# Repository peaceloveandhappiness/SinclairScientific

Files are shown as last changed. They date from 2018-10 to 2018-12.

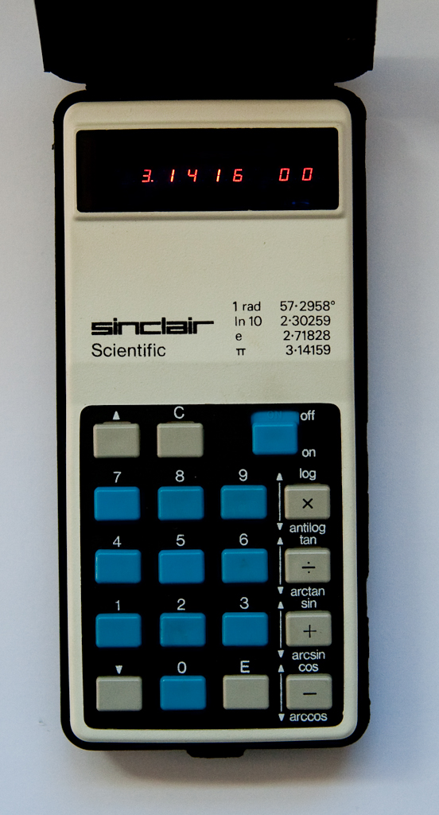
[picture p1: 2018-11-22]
artwork/SinclairScientific.jpg

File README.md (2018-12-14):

# Sinclair Scientific

This is a recreation of the original 1974 Scientific Calculator, the first affordable calculator with more than just + - ÷ ×.

Hewlett Packard had released it’s first “scientific” calculator two years earlier, and despite it costing literally as much as a fairly nice used car, it was a very successful product. Texas Instruments, on the other hand, had a widely available “four function” chip that was the heart of every cheap digital calculator, but was limited to adding, subtracting, multiplying and dividing, with limited precision.

Enter Clive Sinclair and Nigel Searle, who figured out how to use the ultra-meager 320 bytes of instruction space on that TI device to implement sine, asin, cos, acos, tan, atan, log, and antilog, in scientific notation! A feat of hacking that’s mystifying even now.

We have recreated this hallowed machine using an emulator of the TI chip, running the original instructions, at the original speed. It has lots of quirks and issues, some of which are described in this manual, some of which we had fun exploring. Far from diminishing it, these idiosyncrasies, in reality, highlight the amazing achievement that this device represents.

Enjoy!

## Inspiration

This work was inspired by and largely based upon [ArduinoEnigma's similar project](https://gitlab.com/arduinoenigma/ArduinoNanoSinclairScientificCalculator), which was inspired by [Ken Shirriff's Sinclair Scientific Calculator Simulator](http://righto.com/sinclair). The hardware design is based upon [Adafruit's Feather M0](https://github.com/adafruit/Adafruit-Feather-M0-Basic-Proto-PCB), as well as [ArduinoEnigma's hardware designs](https://hackaday.io/project/91895-sinclair-scientific-calculator-emulator). The firmware used in this project is based on [ArduinoEnigma's SinclairScientific7 code](https://gitlab.com/arduinoenigma/ArduinoNanoSinclairScientificCalculator/tree/master/SinclairScientific7) and [Adafruit's SAMD toolchain](https://github.com/adafruit/ArduinoCore-samd).

* [Ken Shirriff's Simulator](http://files.righto.com/calculator/sinclair_scientific_simulator.html)
* [ArduinoEnigma's Arduino Code](https://github.com/arduinoenigma/ArduinoNanoSinclairScientificCalculator)
* [ArduinoEnigma's Hackster Guide](https://www.hackster.io/arduinoenigma/sinclair-scientific-calculator-emulator-a11dba)
* [ArduinoEnigma's Hackaday Guide](https://hackaday.io/project/91895-sinclair-scientific-calculator-emulator)
* [ArduinoEnigma's Tindie Page](https://www.tindie.com/products/ArduinoEnigma/sinclair-scientific-calculator-emulator/)
* [Adafruit's Feather M0](https://github.com/adafruit/Adafruit-Feather-M0-Basic-Proto-PCB)

## Credits

* Thank you Joerg Woerner of [Datamath Calculator Museum](www.datamath.org/) for finding and scanning the original [Sinclair Scientific Operating Manual](www.datamath.net/Manuals_Others/Sinclair_Scientific_GB.pdf).
* Thank you [Katherine Wasserman](www.wass.net/) for finding the original [Sinclair Scientific Assembly Manual](www.wass.net/manuals/Sinclair%20Scientific%20Assembly.pdf)
* Thank you [ArduinoEnigma](www.arduinoenigma.blogspot.com) for starting the project and making the previous iterations. Awesome work!
* Thank you [Ken Shirriff](www.righto.com) for your immense talents and hard work, not only on this emulator but on lots of interesting stuff.
* Thank you [Adafruit](www.adafruit.com) for all of your incredible open source work.

## Additional Information

* [Wikipedia Page for the Sinclair Scientific](https://en.wikipedia.org/wiki/Sinclair_Scientific)
* [Historical Info about the Sinclair Scientific](http://rk.nvg.ntnu.no/sinclair/calculators/scientific.htm)
* [Technical Info about the Sinclair Scientific](http://www.vintagecalculators.com/html/scientific_-_giant_scientific.html)
* [Sinclair Scientific Operating Manual](http://www.datamath.net/Manuals_Others/Sinclair_Scientific_GB.pdf)
* [Sinclair Scientific Assembly Manual](http://www.wass.net/manuals/Sinclair%20Scientific%20Assembly.pdf)

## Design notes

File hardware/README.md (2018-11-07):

# Sinclair Scientific Hardware

## Revision History

### v1A

* Initial revision, based on [ArduinoEnigma's design](https://cdn.hackaday.io/files/918953931635680/V5%20Schematic.png)

### v1B

* Replaced Arduino NANO MCU with one used by Adafruit Feather M0 (SAMD21G18)
* Replaced alkaline batteries with LiPo battery
* Added LiPo battery charging circuit
* Changed LED resistor values to work with 3.3V
* Changed 7-segment displays to mount on a daughter board to allow them to be flush mounted with the faceplate
* Swapped existing tactile buttons for ones that can be used with button caps
* Swapped existing ON/OFF switch for more comfortable one
* Added charging LED that can be seen by user
* Moved LED segments [B, E] to [D0, D1] pins to allow button input lines to use [D8, D9] exclusively

### v1C

* Fixed footprint for flash memory IC
* Changed button spacing to match original sinclair dimensions
* Replaced power switch with SMT device

### Future Changes

* Consider using LED or 7-segment display driver
  * [MAX6954](https://www.maximintegrated.com/en/app-notes/index.mvp/id/3210)
  * [MAX6957](https://www.maximintegrated.com/en/products/power/display-power-control/MAX6957.html)
  * [MAX7301](https://www.maximintegrated.com/en/products/interface/controllers-expanders/MAX7301.html)
  * Maxim has many other parts that may work better

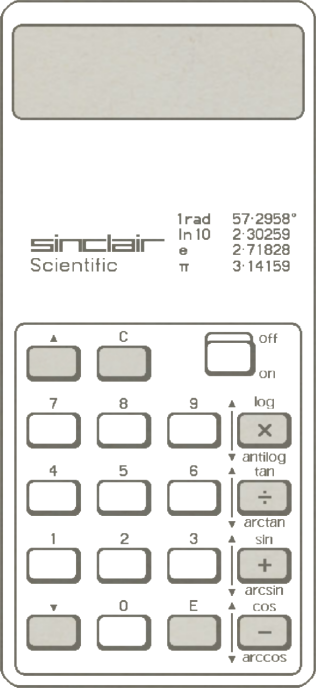
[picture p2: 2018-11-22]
docs/Sinclair Scientific Wireframe.png

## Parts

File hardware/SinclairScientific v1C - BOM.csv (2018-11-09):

Qty | DNP | Value | MFG | MPN | PN-DK | Device | Package | Parts | Description
2 |  | 22p | Murata Electronics North America | GQM1875C2E220JB12D | 490-16699-1-ND | C-USC0603 | C0603 | C2, C4 | CAP CER 22PF 250V NP0 0603
5 |  | 100n | AVX Corporation | 06035C104K4Z4A | 478-10679-1-ND | C-USC0603 | C0603 | C5, C9, C10, C11, C15 | CAP CER 0.1UF 50V X7R 0603
4 |  | 1u | TDK Corporation | C1608X7R1C105M080AC | 445-5131-1-ND | C-USC0603 | C0603 | C1, C7, C12, C14 | CAP CER 1UF 16V X7R 0603
4 |  | 10u | Murata Electronics North America | GRM21BR61C106KE15K | 490-6473-1-ND | C-USC0805 | C0805 | C3, C6, C8, C13 | CAP CER 10UF 16V X5R 0805
8 |  | 150 | Yageo | RC0603FR-07150RL | 311-150HRCT-ND | R-US_R0603 | R0603 | R5, R6, R9, R10, R11, R12, R13, R14 | RES SMD 150 OHM 1% 1/10W 0603
12 |  | 1k | Yageo | RC0603FR-071KL | 311-1.00KHRCT-ND | R-US_R0603 | R0603 | R1, R2, R7, R15, R16, R17, R18, R19, R20, R21, R22, R23 | RES SMD 1K OHM 1% 1/10W 0603
3 |  | 3.3k | Yageo | RC0603FR-073K3L | 311-3.30KHRCT-ND | R-US_R0603 | R0603 | R3, R4, R8 | RES SMD 3.3K OHM 1% 1/10W 0603
1 |  | MBR120 | ON Semiconductor | MBR120VLSFT1G | MBR120VLSFT1GOSCT-ND | DIODE-SCHOTTKYSOD-123 | SOD-123 | D1 | DIODE SCHOTTKY 20V 1A SOD123FL
2 |  | GREEN | Lite-On Inc. | LTST-C170GKT | 160-1179-1-ND | LED0805_NOOUTLINE | CHIPLED_0805_NOOUTLINE | HB, L1 | LED GREEN CLEAR SMD
1 |  | GREEN-RA | Lite-On Inc. | LTST-S220KGKT | 160-1468-1-ND | LED0805_NOOUTLINE | CHIPLED_0805_NOOUTLINE | CHG | LED GREEN CLEAR CHIP SMD R/A
17 |  | FDV303N | ON Semiconductor | FDV303N | FDV303NCT-ND | NMOSSOT23-FDV303N | SOT-23 | T1, T2, T3, T4, T5, T6, T7, T8, T9, T10, T11, T12, T13, T14, T15, T16, T17 | MOSFET N-CH 25V 680MA SOT-23
1 |  | 500mA | Bel Fuse Inc. | 0ZCK0050FF2E | 507-1813-1-ND | R-US_R0805 | R0805 | F1 | PTC RESET FUSE 6V 500MA 0805
1 |  | 32.768 | ECS Inc. | ECS-.327-12.5-34B-TR | XC1617CT-ND | XTAL-3.2X1.5 | XTAL3215 | X2 | CRYSTAL 32.7680KHZ 12.5PF SMD
1 |  | ATSAMD21G18 | Microchip Technology | ATSAMD21G18A-AUT | ATSAMD21G18A-AUTCT-ND | ATSAMD21J_QFP | TQFP48_7MM | U4 | IC MCU 32BIT 256KB FLASH 48TQFP
1 |  | MCP73831T-2ACI/OT | Microchip Technology | MCP73831T-2ACI/OT | MCP73831T-2ACI/OTCT-ND | MCP73831/2 | SOT23-5 | U3 | IC CONTROLLR LI-ION 4.2V SOT23-5
1 |  | SPX3819-3.3 | MaxLinear, Inc. | SPX3819M5-L-3-3/TR | 1016-1873-1-ND | VREG_SOT23-5 | SOT23-5 | U2 | IC REG LINEAR 3.3V 500MA SOT23-5
1 |  | W25Q128JVWSON_6X5 | Winbond Electronics | W25Q128JVPIM | W25Q128JVPIMCT-ND | W25Q128JVWSON_6X5 | SON127P600X500X80-9N | U5 | IC FLASH 128M SPI 133MHZ 8WSON
1 |  | SPDT_SLIDE-CB-SB-12B | Nidec Copal Electronics | CL-SB-12B-01T | 563-1318-1-ND | SPDT_SLIDE-CB-SB-12B | CL-SB-12B | S1 | SWITCH SLIDE SPDT 200MA 12V
18 |  | SPST_TACT-TL3301SPF | E-Switch | TL3301SPF260QG | EG1870CT-ND | SPST_TACT-TL3301SPF | TACT_6X6 | SW-0, SW-1, SW-2, SW-3, SW-4, SW-5, SW-6, SW-7, SW-8, SW-9, SW-C, SW-DIV, SW-DWN, SW-E, SW-MINUS, SW-MULT, SW-PLUS, SW-UP | SWITCH TACTILE SPST-NO 0.05A 12V
1 |  | USB-MICRO | Amphenol | 10118192-0001LF | 609-4613-1-ND | USB-MICRO | USB-10118192-0001LF | J3 | CONN USB MICRO B RECPT SMT R/A
1 |  | JSTPH | JST Sales America Inc. | S2B-PH-SM4-TB(LF)(SN) | 455-1749-1-ND | CON_JST_PH_2PIN | JSTPH2 | J1 | CONN HEADER 18POS 2MM VERT SMD
1 |  | 87759-1850 | Molex | 87759-1850 | WM18656-ND | PINHD-2X9-2MM-SMD | 2X09-2MM-SMD | J2 | CONN HEADER 18POS 2MM VERT SMD
18 | DNP | SW-CAP_1SXXX | E-Switch | 1SWHT | EG4365-ND | SW-CAP_1SXXX | SW-CAP_1SWXXX | SW-0_CAP, SW-1_CAP, SW-2_CAP, SW-3_CAP, SW-4_CAP, SW-5_CAP, SW-6_CAP, SW-7_CAP, SW-8_CAP, SW-9_CAP, SW-C_CAP, SW-DIV_CAP, SW-DWN_CAP, SW-E_CAP, SW-MINUS_CAP, SW-MULT_CAP, SW-PLUS_CAP, SW-UP_CAP | CAP PUSHBUTTON SQUARE
1 | DNP | TC2030-IDC-NL | Tag-Connect | TC2030-IDC-NL | TC2030-IDC-NL | TC2030-IDC-NL | TC2030-IDC-NL | TC1 | Tag-Connect In Circuit Programming & Debug Cable 6 Pin

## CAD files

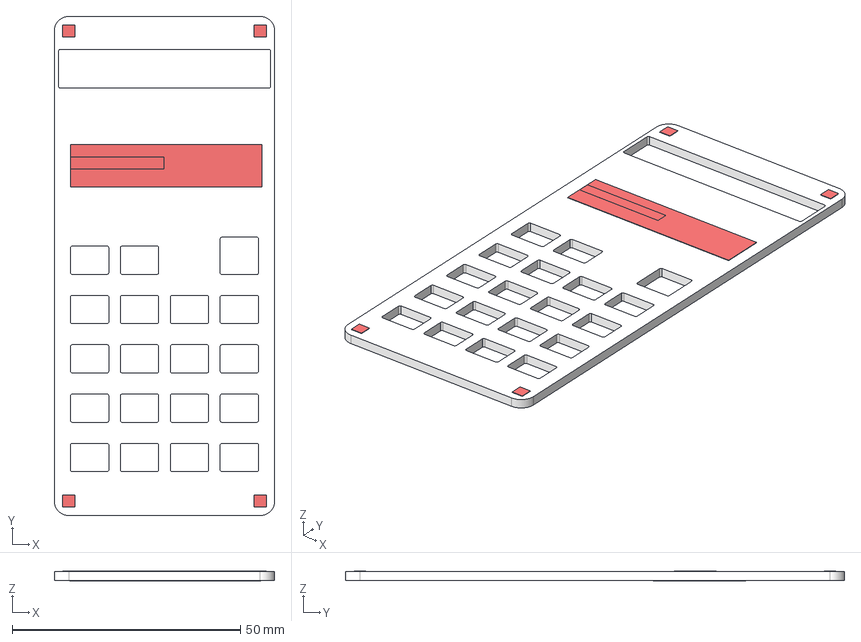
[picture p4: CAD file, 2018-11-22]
mechanical/faceplate.step
48.3 x 109.2 x 2.20 mm
Board
HOLE_3-48_NO-STOP x 4
SILK_REF_TEXT
SILK_SINCLAIR_LOGO
SILK_SIGNATURES

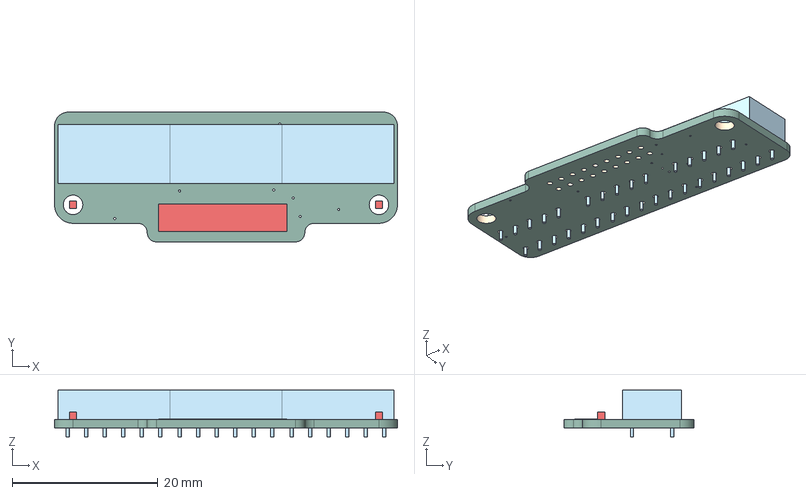
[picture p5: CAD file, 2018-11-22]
mechanical/display-board.step
47.0 x 17.8 x 6.44 mm
Board
LED_3X7-SEGMENT x 3
2X09-2MM
HOLE_3-48 x 2

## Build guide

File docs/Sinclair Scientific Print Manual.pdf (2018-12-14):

© 2011 Joerg Woerner
Datamath Calculator Museum

© 2011 Joerg Woerner
Datamath Calculator Museum

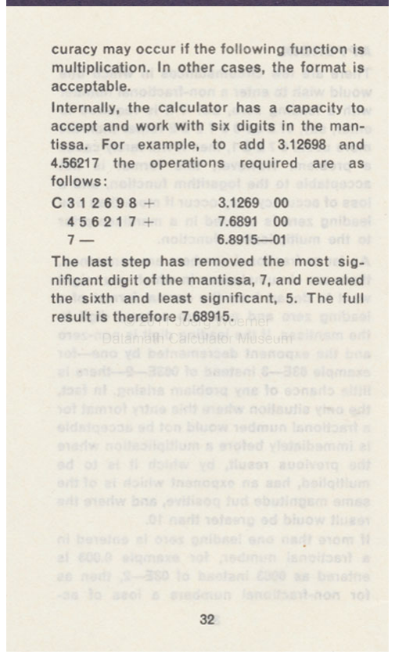
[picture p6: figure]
© 2011 Joerg Woerner Datamath Calculator Museum

© 2011 Joerg Woerner
Datamath Calculator Museum

© 2011 Joerg Woerner
Datamath Calculator Museum

You are holding the (slightly modified) original 1974 manual for the Sinclair Scientific Calculator, the first affordable calculator with more than just + - ÷ ×.

Hewlett Packard had released it’s first “scientific” calculator two years earlier, and despite it costing literally as much as a fairly nice used car, it was a very successful product. Texas Instruments, on the other hand, had widely available “four function” chip that was the heart of every cheap digital calculator, but was limited to adding, subtracting, multiplying and dividing, with limited precision.

Enter Sinclair, who figured out how to use the ultra-meager 320 bytes of instruction space on that TI device to implement sine, asin, cos, acos, tan, atan, log, and antilog, in scientific notation! A feat of hacking that’s mystifying even now.

We have recreated this hallowed machine using an emulator of the TI chip, running the original instructions, at the original speed. It has lots of quirks and issues, some of which are described in this manual, some of which we had fun exploring. Far from diminishing it, these idiosyncrasies, in reality, highlight the amazing achievement that this device represents.

Enjoy!

© 2011 Joerg Woerner
Datamath Calculator Museum

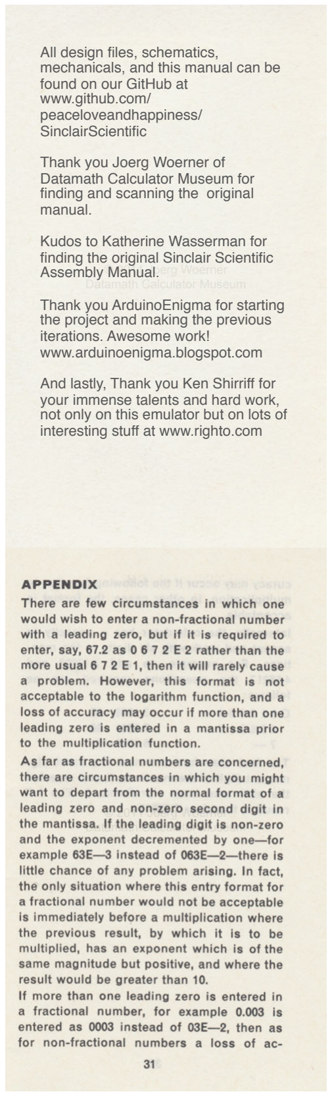
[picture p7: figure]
© 2011 Joerg Woerner Datamath Calculator Museum; All design files, schematics, mechanicals, and this manual can be found on our GitHub at www.github.com/ peaceloveandhappiness/ SinclairScientific; Thank you Joerg Woerner of Datamath Calculator Museum for finding and scanning the original manual.; Kudos to Katherine Wasserman for; Assembly Manual.; Thank you ArduinoEnigma for starting the project and making the previous iterations. Awesome work! www.arduinoenigma.blogspot.com; And lastly, Thank you Ken Shirriff for your immense talents and hard work,; interesting stuff at www.righto.com

finding the original Sinclair Scientific

not only on this emulator but on lots of

© 2011 Joerg Woerner
Datamath Calculator Museum

© 2011 Joerg Woerner
Datamath Calculator Museum

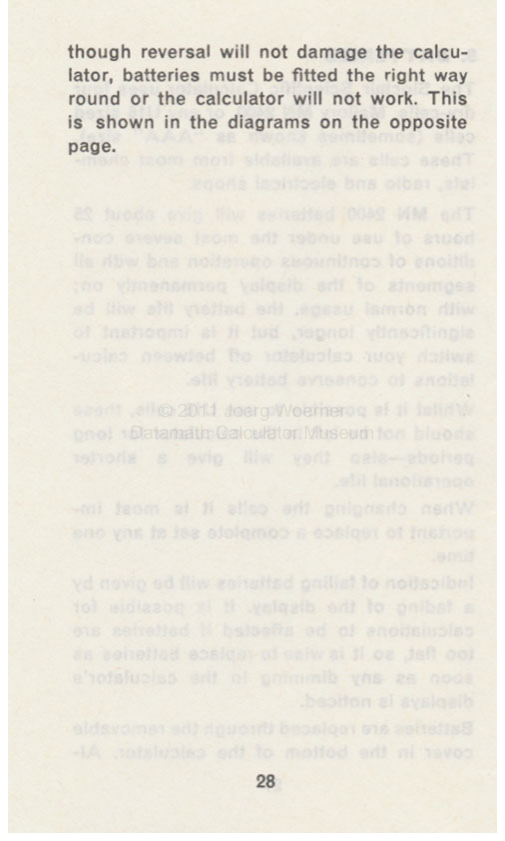
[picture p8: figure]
© 2011 Joerg Woerner Datamath Calculator Museum

© 2011 Joerg Woerner
Datamath Calculator Museum

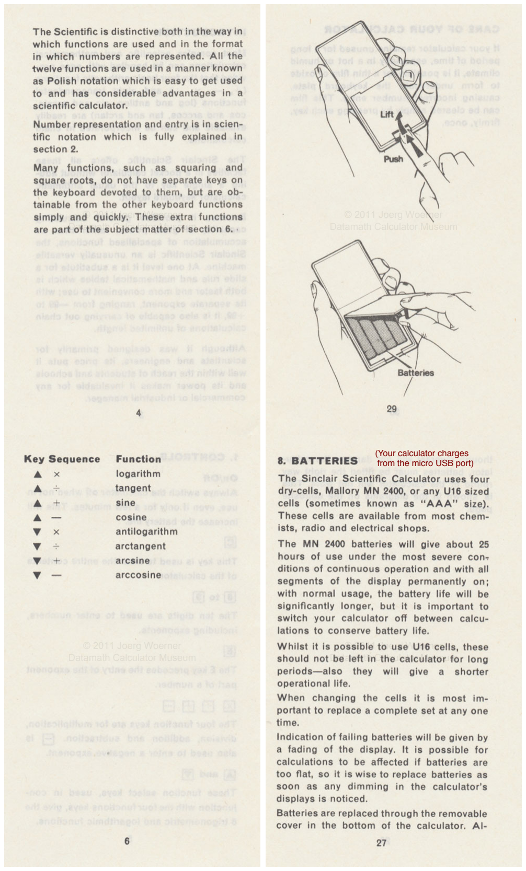
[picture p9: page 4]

© 2011 Joerg Woerner
Datamath Calculator Museum

© 2011 Joerg Woerner
Datamath Calculator Museum

© 2011 Joerg Woerner
Datamath Calculator Museum

© 2011 Joerg Woerner
Datamath Calculator Museum

(Your calculator charges
from the micro USB port)

© 2011 Joerg Woerner
Datamath Calculator Museum

© 2011 Joerg Woerner
Datamath Calculator Museum

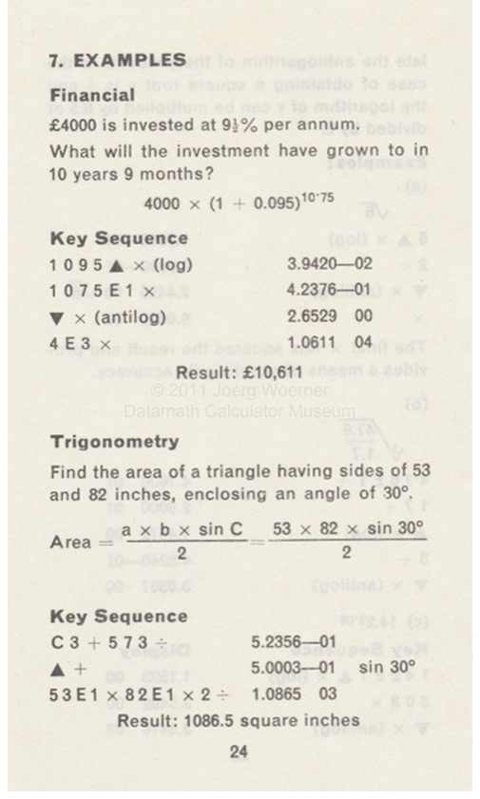
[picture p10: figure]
© 2011 Joerg Woerner Datamath Calculator Museum

© 2011 Joerg Woerner
Datamath Calculator Museum

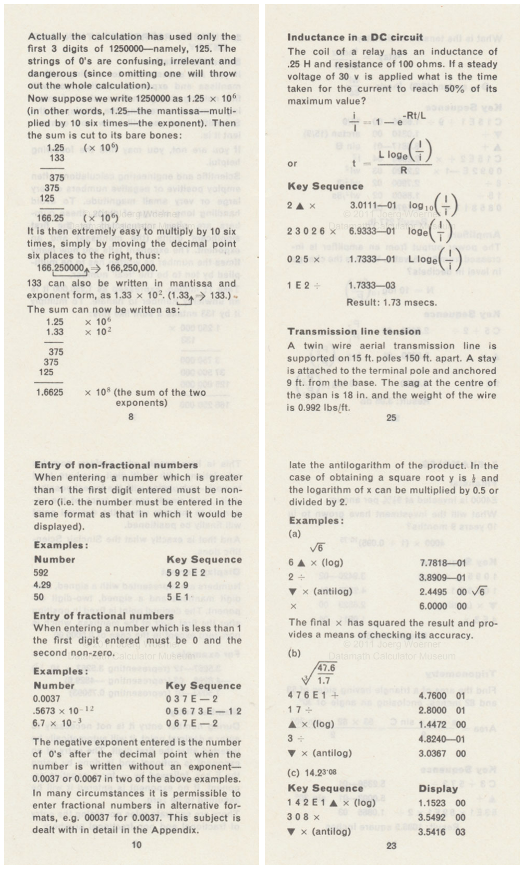
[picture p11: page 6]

© 2011 Joerg Woerner
Datamath Calculator Museum

© 2011 Joerg Woerner
Datamath Calculator Museum

© 2011 Joerg Woerner
Datamath Calculator Museum

© 2011 Joerg Woerner
Datamath Calculator Museum

© 2011 Joerg Woerner
Datamath Calculator Museum

© 2011 Joerg Woerner
Datamath Calculator Museum

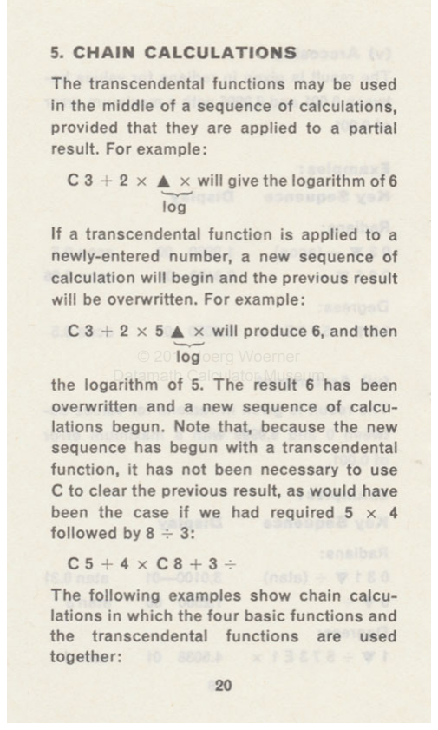
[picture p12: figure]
© 2011 Joerg Woerner Datamath Calculator Museum

© 2011 Joerg Woerner
Datamath Calculator Museum

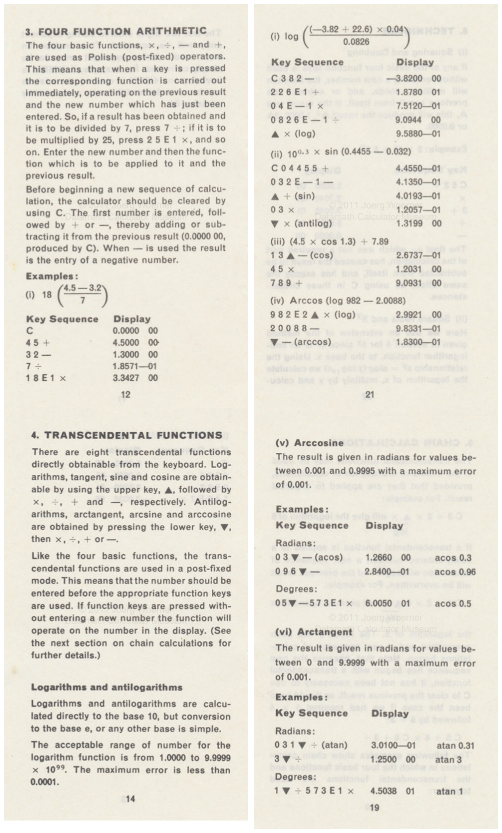
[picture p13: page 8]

© 2011 Joerg Woerner
Datamath Calculator Museum

© 2011 Joerg Woerner
Datamath Calculator Museum

© 2011 Joerg Woerner
Datamath Calculator Museum | © 2011 Joerg Woerner
| Datamath Calculator Museum

© 2011 Joerg Woerner
Datamath Calculator Museum

© 2011 Joerg Woerner
Datamath Calculator Museum

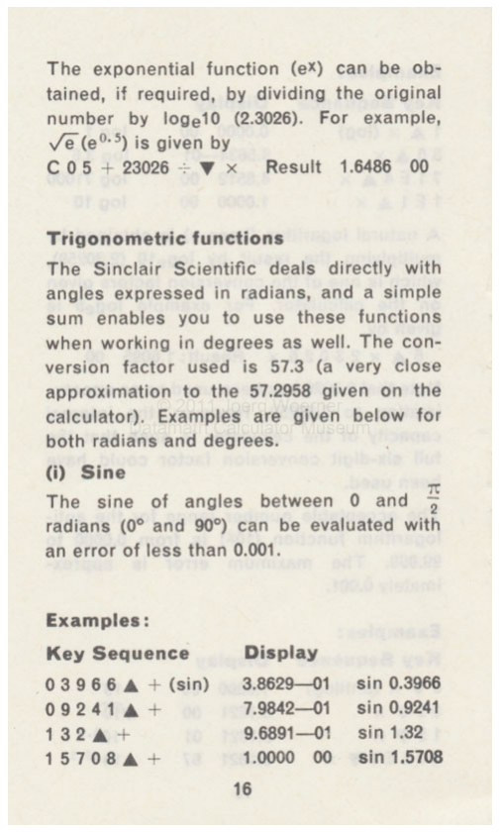
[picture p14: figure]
© 2011 Joerg Woerner Datamath Calculator Museum
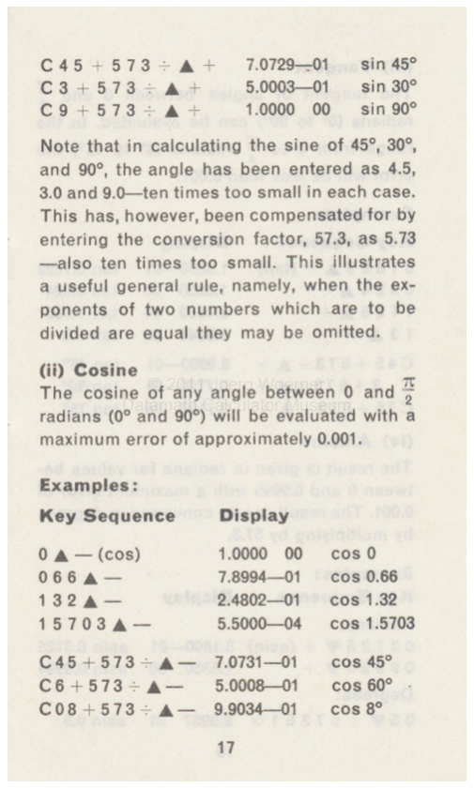
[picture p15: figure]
© 2011 Joerg Woerner Datamath Calculator Museum

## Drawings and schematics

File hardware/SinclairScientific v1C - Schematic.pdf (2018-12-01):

## BATTERY & CHARGING

# 1u1k GND ⁺³V³

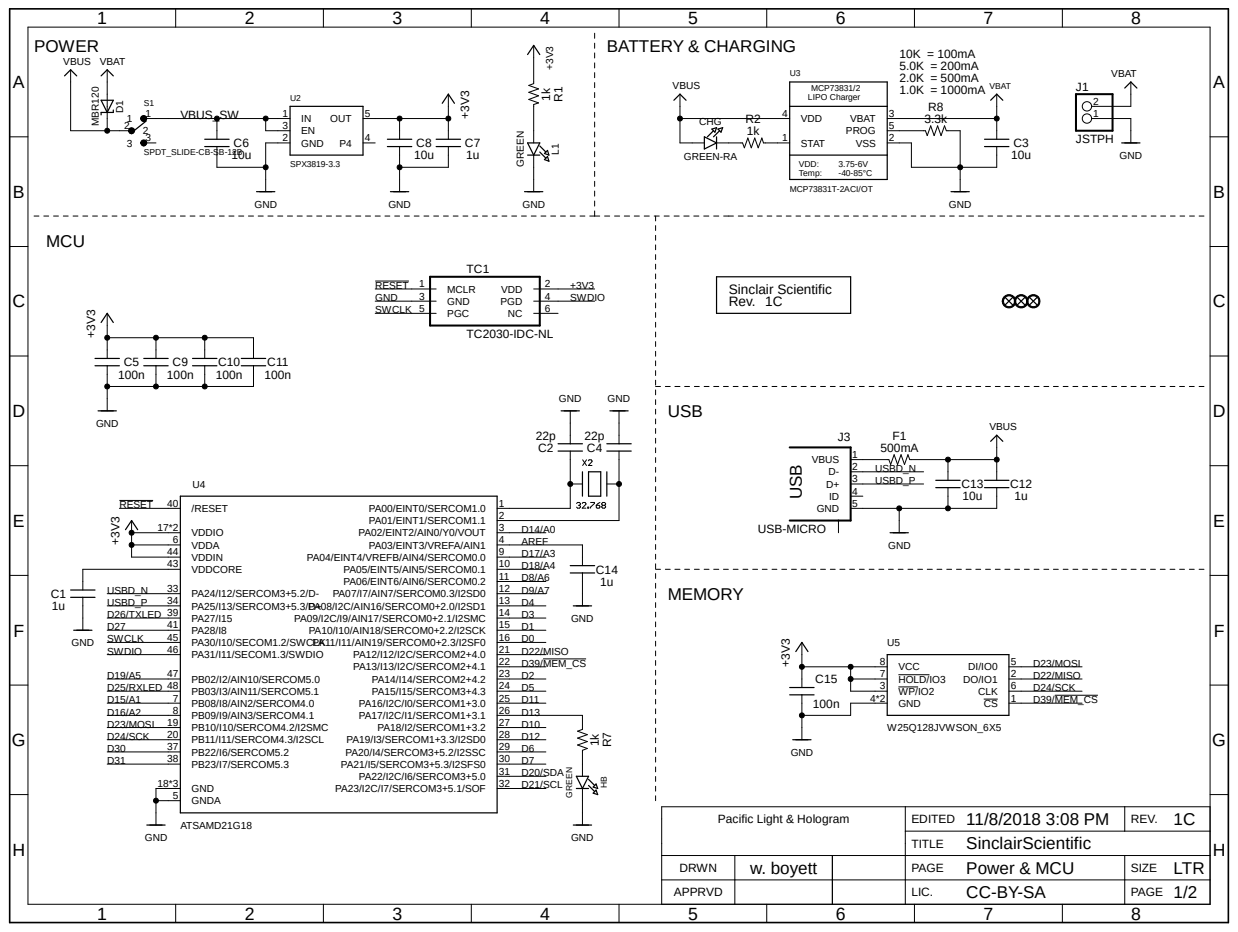
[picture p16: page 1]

DRWN | w. boyett | Power & MCU PAGE | SIZE LTR
APPRVD | | CC-BY-SA LIC. | 1/2 PAGE

## BUTTONS

A

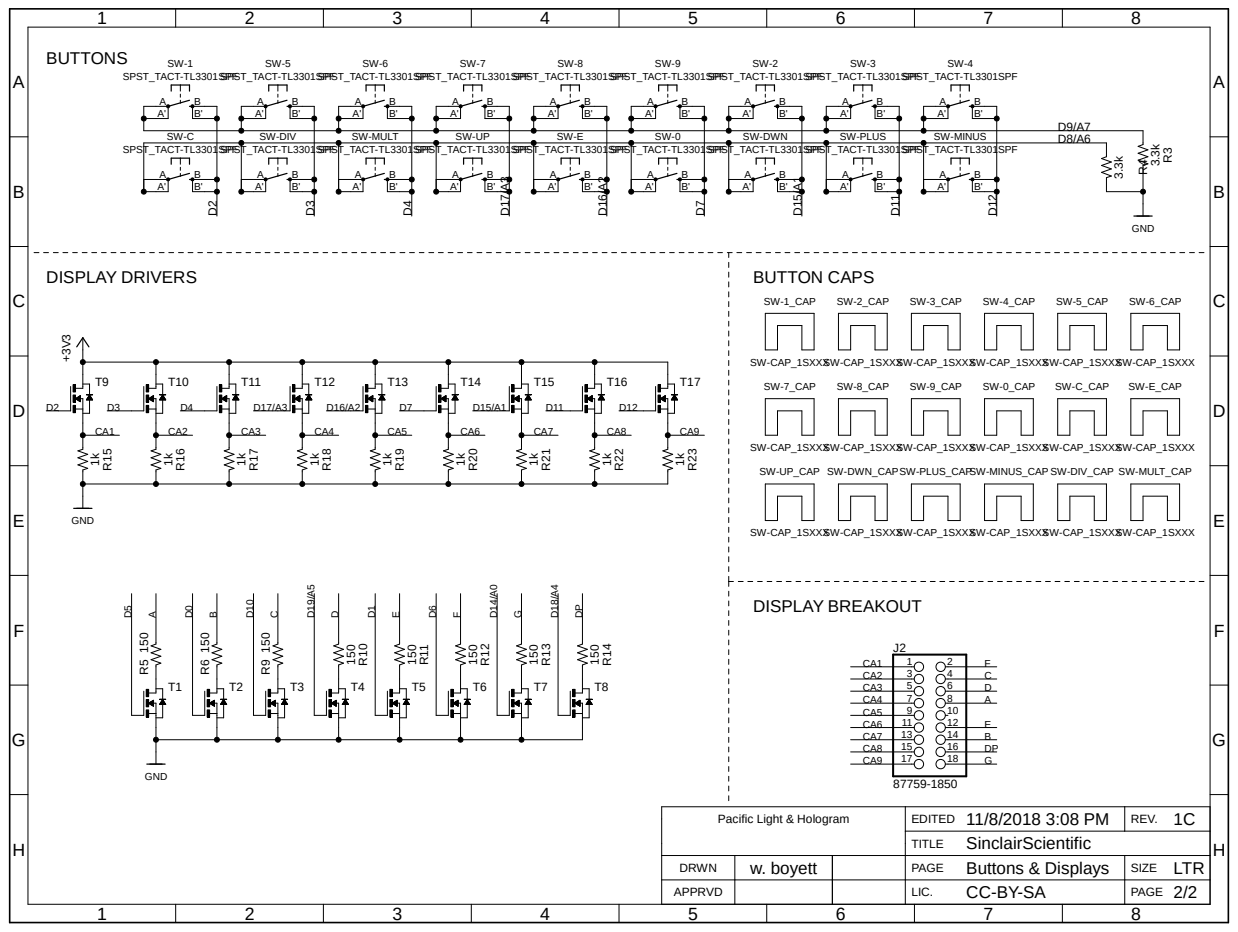
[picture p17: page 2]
DISPLAY DRIVERS; DISPLAY BREAKOUT; BUTTON CAPS 150; 150 GND; 150 1k GND ⁺³V³; SPST_TACT-TL3301SPF SPST_TACT-TL3301SPF SPST_TACT-TL3301SPF SPST_TACT-TL3301SPF SPST_TACT-TL3301SPF SPST_TACT-TL3301SPF SPST_TACT-TL3301SPF SPST_TACT-TL3301SPF SPST_TACT-TL3301SPF; 3.3k 3.3k GND; SW-CAP_1SXXX; SW-CAP_1SXXXSW-CAP_1SXXX; T4 R¹⁰; T5 R¹¹; T6 R¹²; T7 R¹³; T8 R¹⁴; T9 R¹⁵; T10R¹⁶; T11R¹⁷; T12R¹⁸; T13R¹⁹; T14R²⁰; T15R²¹; T16R²²; T17R²³; B' SW-DIV; B' SW-MULT; B' SW-DWN; B' SW-PLUS; B' SW-MINUS; SW-1_CAP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

Pacific Light & Hologram

DRWN | w. boyett | Buttons & Displays PAGE | SIZE LTR
APPRVD | | CC-BY-SA LIC. | 2/2 PAGE

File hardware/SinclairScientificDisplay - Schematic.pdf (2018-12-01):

# LED_3X7-SEGMENT A

LED_CA9 ABCDEFGH | 1 | 2 | 3 | 4 | 5 | 6 | 7 | 8 | ABCDEFGH 1 | 2 | 3 | 4 | 5 | 6 | 7 | 8

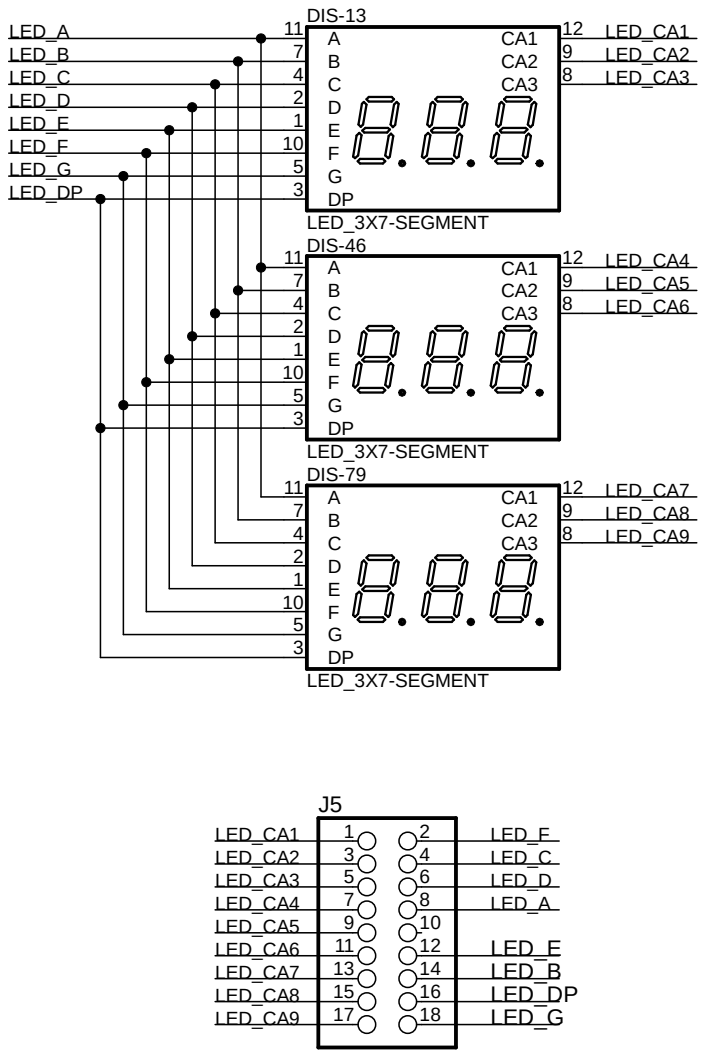
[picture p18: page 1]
LED_3X7-SEGMENT; 8 DIS-13 A; 8 DIS-46 A; 8 DIS-79; LED_A; LED_B; LED_C; LED_D; LED_E; LED_F; LED_G; LED_DP; LED_CA2; LED_CA5; LED_CA3; LED_CA6; LED_CA1; LED_CA4; LED_CA7; LED_CA8; LED_CA9; REV.; TITLE; EDITED; 11/7/2018 9:01 AM SinclairScientificDisplay

Pacific Light & Hologram

DRWN | w. boyett | Displays PAGE | SIZE LTR
APPRVD | | CC-BY-SA LIC. | 1/1 PAGE

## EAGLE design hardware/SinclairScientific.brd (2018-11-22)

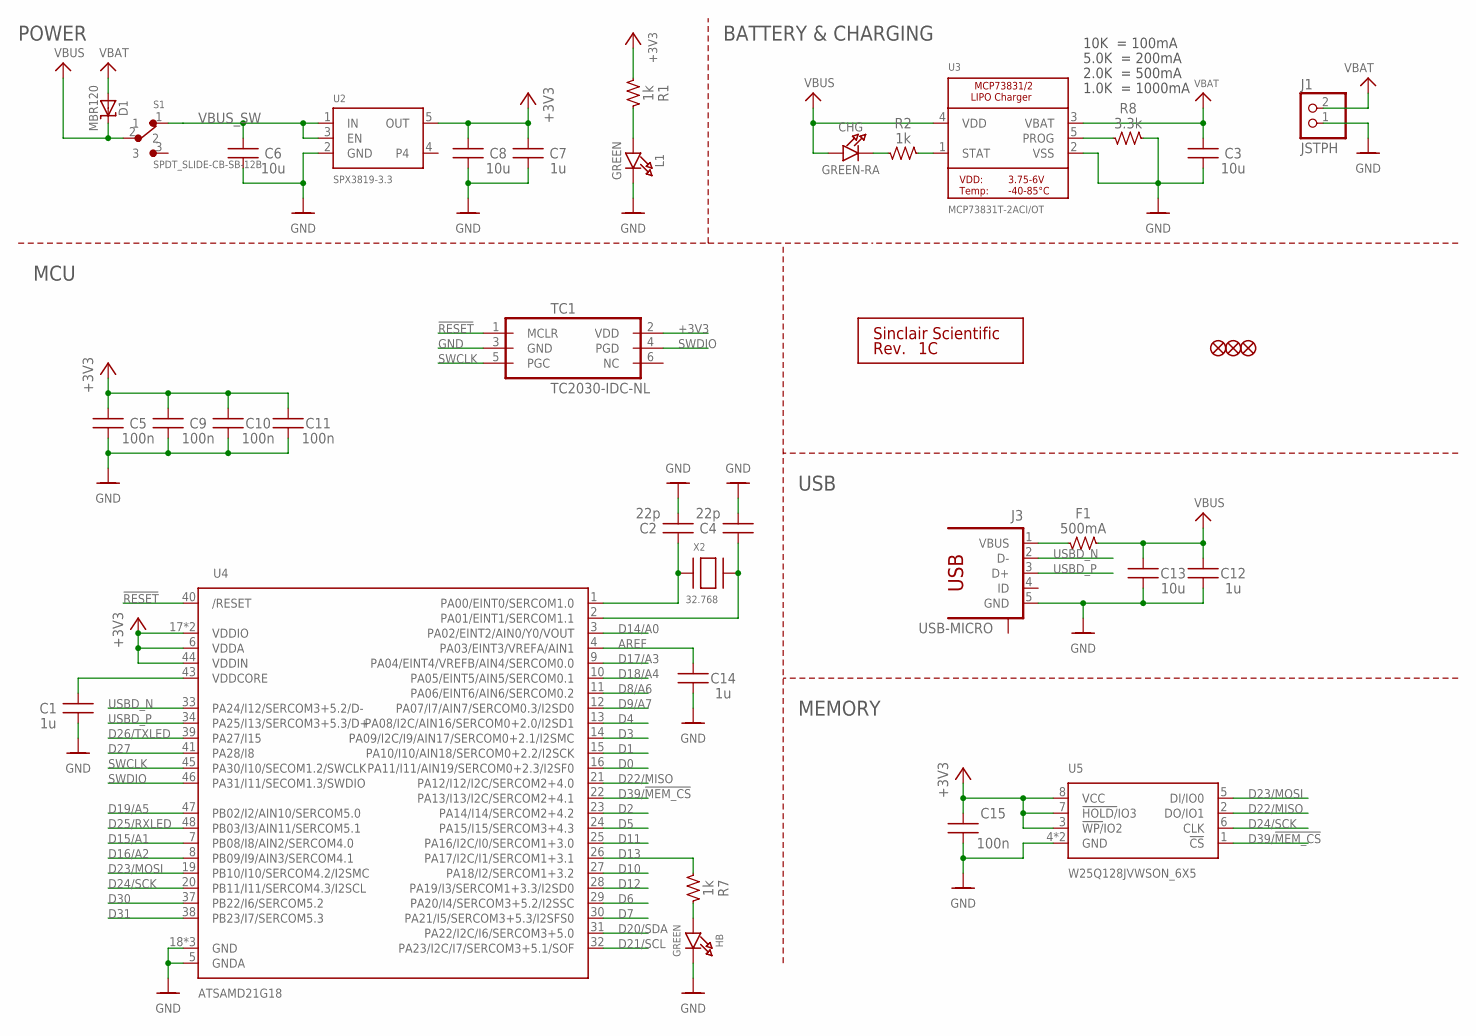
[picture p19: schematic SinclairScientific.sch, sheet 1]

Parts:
C1, C7, C12, C14: 1u; C0603; MPN C1608X7R1C105M080AC
C2, C4: 22p; C0603; MPN GQM1875C2E220JB12D
C3, C6, C8, C13: 10u; C0805; MPN GRM21BR61C106KE15K
C5, C9, C10, C11, C15: 100n; C0603; MPN 06035C104K4Z4A
CHG: GREEN-RA; CHIPLED_0805_NOOUTLINE; MPN LTST-S220KGKT
D1: MBR120; SOD-123; MPN MBR120VLSFT1G
F1: 500mA; R0805; MPN 0ZCK0050FF2E
FID1, FID2, FID3: FIDUCIAL""; FIDUCIAL_1MM
HB: GREEN; CHIPLED_0805_NOOUTLINE; MPN LTST-C170GKT
J1: JSTPH; JSTPH2; MPN S2B-PH-SM4-TB(LF)(SN)
J3: USB-MICRO; USB-10118192-0001LF
L1: GREEN; CHIPLED_0805_NOOUTLINE; MPN LTST-C170GKT
R1, R2, R7: 1k; R0603; MPN RC0603FR-071KL
R8: 3.3k; R0603; MPN RC0603FR-073K3L
S1: SPDT_SLIDE-CB-SB-12B; CL-SB-12B; MPN CL-SB-12B-01T
SILK-QC: SILK_QC
TC1: TC2030-IDC-NL
U2: SPX3819-3.3; SOT23-5; MPN SPX3819M5-L-3-3/TR
U3: MCP73831T-2ACI/OT; SOT23-5; MPN MCP73831T-2ACI/OT
U4: ATSAMD21G18; TQFP48_7MM; MPN ATSAMD21G18A-AUT
U5: W25Q128JVWSON_6X5; SON127P600X500X80-9N; MPN W25Q128JVPIM
X2: 32.768; XTAL3215; MPN ECS-.327-12.5-34B-TR

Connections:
!RESET: TC1.1 (MCLR), U4.40 (/RESET)
+3V3: C5.1, C7.1, C8.1, C9.1, C10.1, C11.1, C15.1, R1.1, TC1.2 (VDD), U2.5 (OUT), U4.6 (VDDA), U4.17 (VDDIO), U4.36 (VDDIO), U4.44 (VDDIN), U5.3 (!WP/!IO2), U5.7 (!HOLD/!IO3), U5.8 (VCC); also elsewhere on the board
AREF: C14.1, U4.4 (PA03/EINT3/VREFA/AIN1)
D0: U4.16 (PA11/I11/AIN19/SERCOM0+2.3/I2SF0); also elsewhere on the board
D1: U4.15 (PA10/I10/AIN18/SERCOM0+2.2/I2SCK); also elsewhere on the board
D2: U4.23 (PA14/I14/SERCOM2+4.2); also elsewhere on the board
D3: U4.14 (PA09/I2C/I9/AIN17/SERCOM0+2.1/I2SMC); also elsewhere on the board
D4: U4.13 (PA08/I2C/AIN16/SERCOM0+2.0/I2SD1); also elsewhere on the board
D5: U4.24 (PA15/I15/SERCOM3+4.3); also elsewhere on the board
D6: U4.29 (PA20/I4/SERCOM3+5.2/I2SSC); also elsewhere on the board
D7: U4.30 (PA21/I5/SERCOM3+5.3/I2SFS0); also elsewhere on the board
D8/A6: U4.11 (PA06/EINT6/AIN6/SERCOM0.2); also elsewhere on the board
D9/A7: U4.12 (PA07/I7/AIN7/SERCOM0.3/I2SD0); also elsewhere on the board
D10: U4.27 (PA18/I2/SERCOM1+3.2); also elsewhere on the board
D11: U4.25 (PA16/I2C/I0/SERCOM1+3.0); also elsewhere on the board
D12: U4.28 (PA19/I3/SERCOM1+3.3/I2SD0); also elsewhere on the board
D13: R7.1, U4.26 (PA17/I2C/I1/SERCOM1+3.1)
D14/A0: U4.3 (PA02/EINT2/AIN0/Y0/VOUT); also elsewhere on the board
D15/A1: U4.7 (PB08/I8/AIN2/SERCOM4.0); also elsewhere on the board
D16/A2: U4.8 (PB09/I9/AIN3/SERCOM4.1); also elsewhere on the board
D17/A3: U4.9 (PA04/EINT4/VREFB/AIN4/SERCOM0.0); also elsewhere on the board
D18/A4: U4.10 (PA05/EINT5/AIN5/SERCOM0.1); also elsewhere on the board
D19/A5: U4.47 (PB02/I2/AIN10/SERCOM5.0); also elsewhere on the board
D20/SDA: U4.31 (PA22/I2C/I6/SERCOM3+5.0)
D21/SCL: U4.32 (PA23/I2C/I7/SERCOM3+5.1/SOF)
D22/MISO: U4.21 (PA12/I12/I2C/SERCOM2+4.0), U5.2 (DO/IO1)
D23/MOSI: U4.19 (PB10/I10/SERCOM4.2/I2SMC), U5.5 (DI/IO0)
D24/SCK: U4.20 (PB11/I11/SERCOM4.3/I2SCL), U5.6 (CLK)
D25/RXLED: U4.48 (PB03/I3/AIN11/SERCOM5.1)
D26/TXLED: U4.39 (PA27/I15)
D27: U4.41 (PA28/I8)
D30: U4.37 (PB22/I6/SERCOM5.2)
D31: U4.38 (PB23/I7/SERCOM5.3)
D39/!MEM_CS: U4.22 (PA13/I13/I2C/SERCOM2+4.1), U5.1 (!CS)
EXTAL32: C2.1, U4.1 (PA00/EINT0/SERCOM1.0), X2.P$1
GND: C1.2, C2.2, C3.2, C4.2, C5.2, C6.2, C7.2, C8.2, C9.2, C10.2, C11.2, C12.2, C13.2, C14.2, C15.2, HB.C, J1.1, J3.5 (GND), L1.C, R8.2, TC1.3 (GND), U2.2 (GND), U3.2 (VSS), U4.5 (GNDA), U4.18 (GND), U4.35 (GND), U4.42 (GND), U5.4 (GND), U5.9 (GND); also elsewhere on the board
unnamed: CHG.C, R2.1
unnamed: HB.A, R7.2
unnamed: R2.2, U3.1 (STAT)
unnamed: R8.1, U3.5 (PROG)
unnamed: L1.A, R1.2
unnamed: F1.1, J3.1 (VBUS)
SWCLK: TC1.5 (PGC), U4.45 (PA30/I10/SECOM1.2/SWCLK)
SWDIO: TC1.4 (PGD), U4.46 (PA31/I11/SECOM1.3/SWDIO)
USBD_N: J3.2 (D-), U4.33 (PA24/I12/SERCOM3+5.2/D-)
USBD_P: J3.3 (D+), U4.34 (PA25/I13/SERCOM3+5.3/D+)
VBAT: C3.1, D1.A, J1.2, U3.3 (VBAT)
VBUS: C12.1, C13.1, CHG.A, D1.C, F1.2, S1.2, U3.4 (VDD)
VBUS_SW: C6.1, S1.1, U2.1 (IN), U2.3 (EN)
VDDCORE: C1.1, U4.43 (VDDCORE)
XTAL32: C4.1, U4.2 (PA01/EINT1/SERCOM1.1), X2.P$2

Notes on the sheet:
POWER
10K = 100mA
5.0K = 200mA
2.0K = 500mA
1.0K = 1000mA
BATTERY & CHARGING
USB
MCU
MEMORY

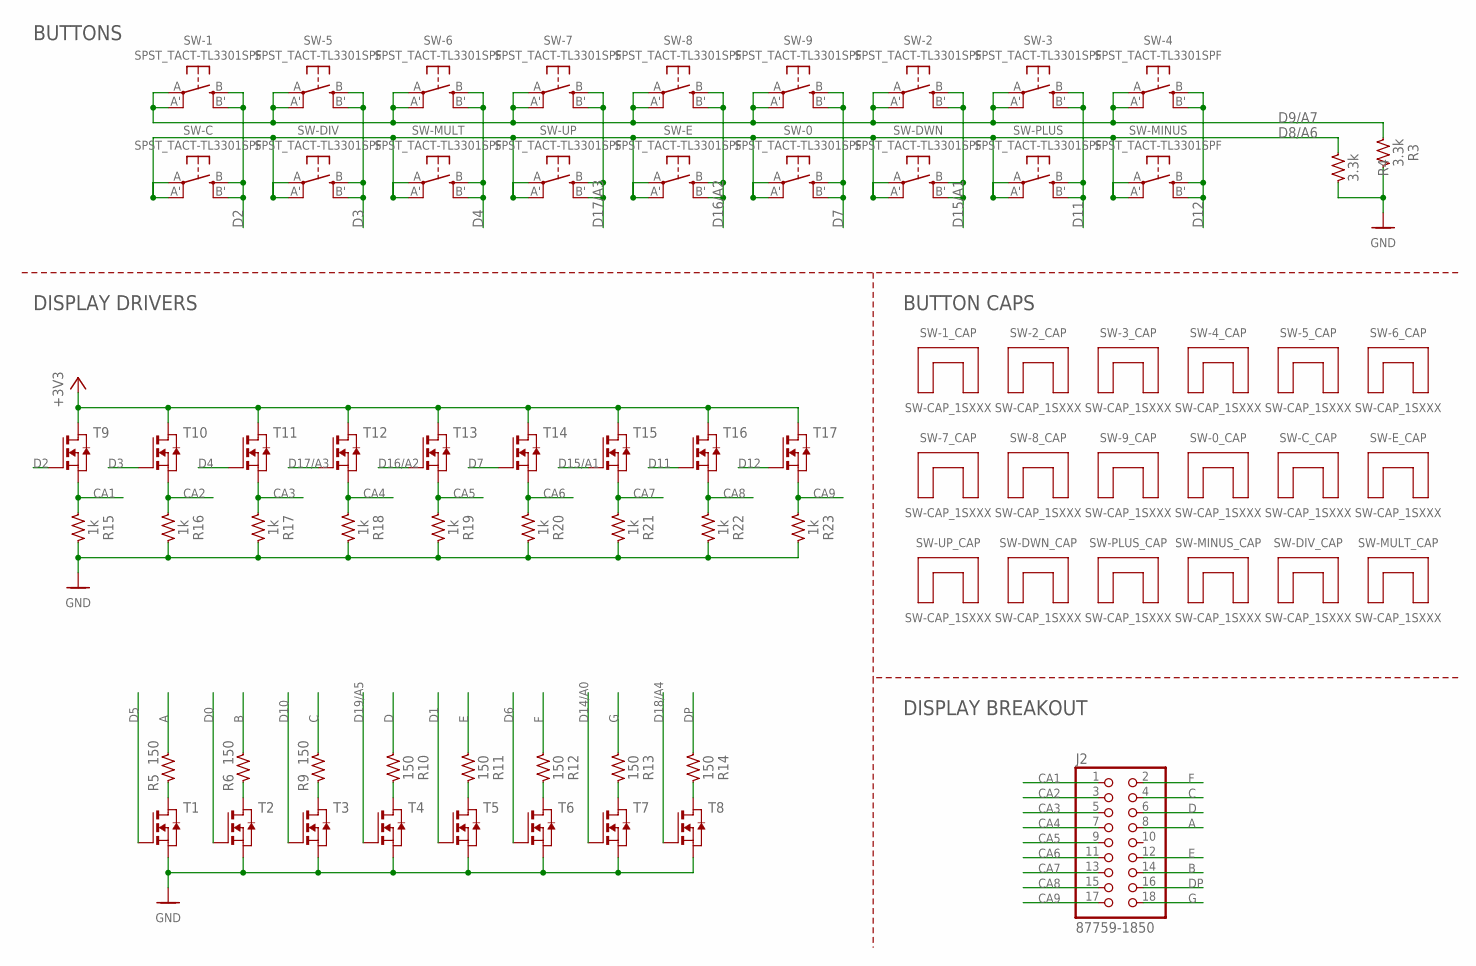
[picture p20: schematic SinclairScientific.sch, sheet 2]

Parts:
J2: 87759-1850; 2X09-2MM-SMD; MPN 87759-1850
R3, R4: 3.3k; R0603; MPN RC0603FR-073K3L
R5, R6, R9, R10, R11, R12, R13, R14: 150; R0603; MPN RC0603FR-07150RL
R15, R16, R17, R18, R19, R20, R21, R22, R23: 1k; R0603; MPN RC0603FR-071KL
SW-0, SW-2, SW-3, SW-4, SW-5, SW-6, SW-7, SW-8, SW-9: SPST_TACT-TL3301SPF; TACT_6X6
SW-0_CAP, SW-1_CAP, SW-2_CAP, SW-3_CAP, SW-4_CAP, SW-5_CAP, SW-6_CAP, SW-7_CAP, SW-8_CAP, SW-9_CAP: SW-CAP_1SXXX; SW-CAP_1SWXXX
SW-1: SPST_TACT-TL3301SPF; TACT_6X6; MPN TL3301SPF260QG
SW-C: SPST_TACT-TL3301SPF; TACT_6X6
SW-C_CAP: SW-CAP_1SXXX; SW-CAP_1SWXXX
SW-DIV: SPST_TACT-TL3301SPF; TACT_6X6
SW-DIV_CAP: SW-CAP_1SXXX; SW-CAP_1SWXXX
SW-DWN: SPST_TACT-TL3301SPF; TACT_6X6
SW-DWN_CAP: SW-CAP_1SXXX; SW-CAP_1SWXXX
SW-E: SPST_TACT-TL3301SPF; TACT_6X6
SW-E_CAP: SW-CAP_1SXXX; SW-CAP_1SWXXX
SW-MINUS: SPST_TACT-TL3301SPF; TACT_6X6
SW-MINUS_CAP: SW-CAP_1SXXX; SW-CAP_1SWXXX
SW-MULT: SPST_TACT-TL3301SPF; TACT_6X6
SW-MULT_CAP: SW-CAP_1SXXX; SW-CAP_1SWXXX
SW-PLUS: SPST_TACT-TL3301SPF; TACT_6X6
SW-PLUS_CAP: SW-CAP_1SXXX; SW-CAP_1SWXXX
SW-UP: SPST_TACT-TL3301SPF; TACT_6X6
SW-UP_CAP: SW-CAP_1SXXX; SW-CAP_1SWXXX
T1, T2, T3, T4, T5, T6, T7, T8, T10, T11, T12, T13, T14, T15, T16, T17: NMOSSOT23-FDV303N; SOT-23
T9: NMOSSOT23-FDV303N; SOT-23; MPN FDV303N

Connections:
+3V3: T9.1 (D), T10.1 (D), T11.1 (D), T12.1 (D), T13.1 (D), T14.1 (D), T15.1 (D), T16.1 (D), T17.1 (D); also elsewhere on the board
A: J2.8, R5.1
B: J2.14, R6.1
C: J2.4, R9.1
CA1: J2.1, R15.1, T9.2 (S)
CA2: J2.3, R16.1, T10.2 (S)
CA3: J2.5, R17.1, T11.2 (S)
CA4: J2.7, R18.1, T12.2 (S)
CA5: J2.9, R19.1, T13.2 (S)
CA6: J2.11, R20.1, T14.2 (S)
CA7: J2.13, R21.1, T15.2 (S)
CA8: J2.15, R22.1, T16.2 (S)
CA9: J2.17, R23.1, T17.2 (S)
D: J2.6, R10.1
D0: T2.3 (G); also elsewhere on the board
D1: T5.3 (G); also elsewhere on the board
D2: SW-1.B (S), SW-1.B' (S1), SW-C.B (S), SW-C.B' (S1), T9.3 (G); also elsewhere on the board
D3: SW-5.B (S), SW-5.B' (S1), SW-DIV.B (S), SW-DIV.B' (S1), T10.3 (G); also elsewhere on the board
D4: SW-6.B (S), SW-6.B' (S1), SW-MULT.B (S), SW-MULT.B' (S1), T11.3 (G); also elsewhere on the board
D5: T1.3 (G); also elsewhere on the board
D6: T6.3 (G); also elsewhere on the board
D7: SW-0.B (S), SW-0.B' (S1), SW-9.B (S), SW-9.B' (S1), T14.3 (G); also elsewhere on the board
D8/A6: R4.1, SW-0.A, SW-0.A' (P1), SW-C.A, SW-C.A' (P1), SW-DIV.A, SW-DIV.A' (P1), SW-DWN.A, SW-DWN.A' (P1), SW-E.A, SW-E.A' (P1), SW-MINUS.A, SW-MINUS.A' (P1), SW-MULT.A, SW-MULT.A' (P1), SW-PLUS.A, SW-PLUS.A' (P1), SW-UP.A, SW-UP.A' (P1); also elsewhere on the board
D9/A7: R3.1, SW-1.A, SW-1.A' (P1), SW-2.A, SW-2.A' (P1), SW-3.A, SW-3.A' (P1), SW-4.A, SW-4.A' (P1), SW-5.A, SW-5.A' (P1), SW-6.A, SW-6.A' (P1), SW-7.A, SW-7.A' (P1), SW-8.A, SW-8.A' (P1), SW-9.A, SW-9.A' (P1); also elsewhere on the board
D10: T3.3 (G); also elsewhere on the board
D11: SW-3.B (S), SW-3.B' (S1), SW-PLUS.B (S), SW-PLUS.B' (S1), T16.3 (G); also elsewhere on the board
D12: SW-4.B (S), SW-4.B' (S1), SW-MINUS.B (S), SW-MINUS.B' (S1), T17.3 (G); also elsewhere on the board
D14/A0: T7.3 (G); also elsewhere on the board
D15/A1: SW-2.B (S), SW-2.B' (S1), SW-DWN.B (S), SW-DWN.B' (S1), T15.3 (G); also elsewhere on the board
D16/A2: SW-8.B (S), SW-8.B' (S1), SW-E.B (S), SW-E.B' (S1), T13.3 (G); also elsewhere on the board
D17/A3: SW-7.B (S), SW-7.B' (S1), SW-UP.B (S), SW-UP.B' (S1), T12.3 (G); also elsewhere on the board
D18/A4: T8.3 (G); also elsewhere on the board
D19/A5: T4.3 (G); also elsewhere on the board
DP: J2.16, R14.1
E: J2.12, R11.1
F: J2.2, R12.1
G: J2.18, R13.1
GND: R3.2, R4.2, R15.2, R16.2, R17.2, R18.2, R19.2, R20.2, R21.2, R22.2, R23.2, T1.2 (S), T2.2 (S), T3.2 (S), T4.2 (S), T5.2 (S), T6.2 (S), T7.2 (S), T8.2 (S); also elsewhere on the board
unnamed: R5.2, T1.1 (D)
unnamed: R6.2, T2.1 (D)
unnamed: R9.2, T3.1 (D)
unnamed: R10.2, T4.1 (D)
unnamed: R11.2, T5.1 (D)
unnamed: R12.2, T6.1 (D)
unnamed: R13.2, T7.1 (D)
unnamed: R14.2, T8.1 (D)

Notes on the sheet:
BUTTONS
DISPLAY DRIVERS
DISPLAY BREAKOUT
BUTTON CAPS

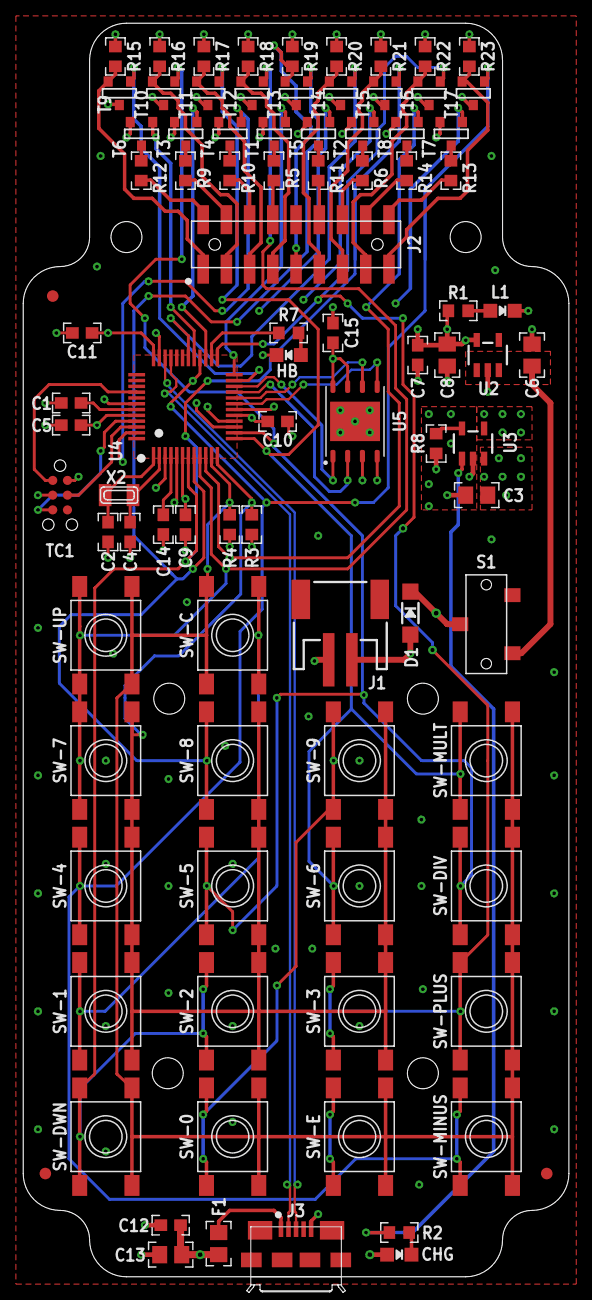
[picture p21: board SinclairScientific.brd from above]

Board: 4 copper layers, 47.0 x 108.0 mm, 117 parts (2 on the bottom side), 69 nets.

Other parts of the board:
U$17: LOGO_PLH_2700
U$50, U$51, U$52, U$53, U$54, U$55: HOLE_3-48

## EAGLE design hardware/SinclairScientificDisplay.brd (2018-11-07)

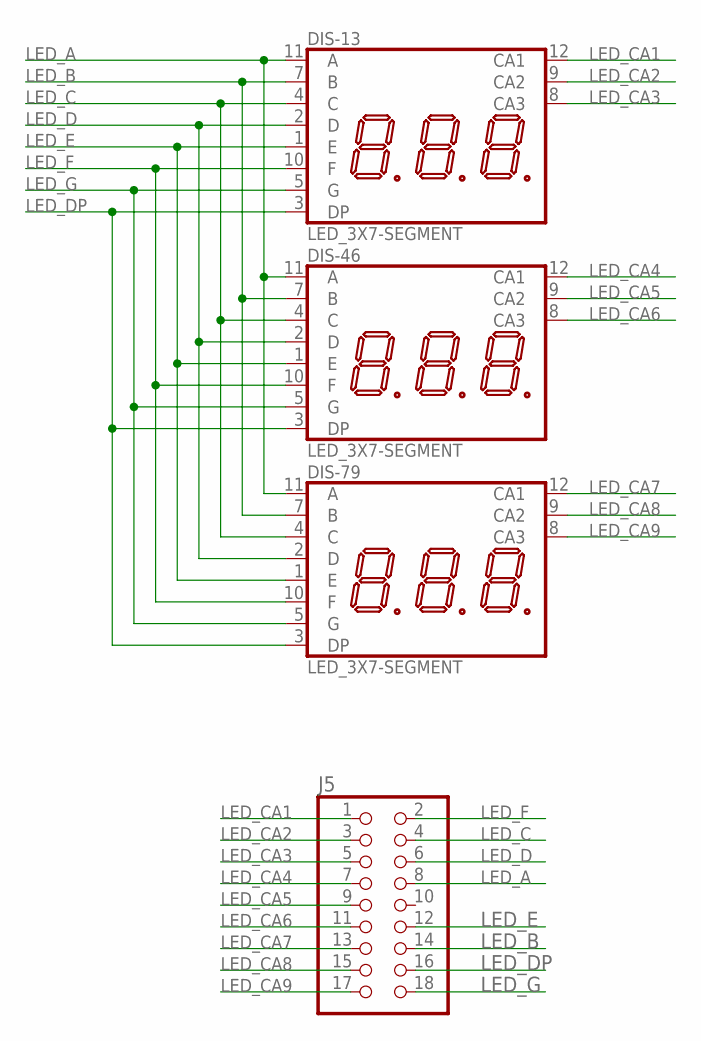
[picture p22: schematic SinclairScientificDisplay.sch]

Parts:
DIS-13, DIS-46, DIS-79: LED_3X7-SEGMENT; 2352B
J5: PINHD-2X9-2MM; 2X09-2MM

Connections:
LED_A: DIS-13.11 (A), DIS-46.11 (A), DIS-79.11 (A), J5.8
LED_B: DIS-13.7 (B), DIS-46.7 (B), DIS-79.7 (B), J5.14
LED_C: DIS-13.4 (C), DIS-46.4 (C), DIS-79.4 (C), J5.4
LED_CA1: DIS-13.12 (CA1), J5.1
LED_CA2: DIS-13.9 (CA2), J5.3
LED_CA3: DIS-13.8 (CA3), J5.5
LED_CA4: DIS-46.12 (CA1), J5.7
LED_CA5: DIS-46.9 (CA2), J5.9
LED_CA6: DIS-46.8 (CA3), J5.11
LED_CA7: DIS-79.12 (CA1), J5.13
LED_CA8: DIS-79.9 (CA2), J5.15
LED_CA9: DIS-79.8 (CA3), J5.17
LED_D: DIS-13.2 (D), DIS-46.2 (D), DIS-79.2 (D), J5.6
LED_DP: DIS-13.3 (DP), DIS-46.3 (DP), DIS-79.3 (DP), J5.16
LED_E: DIS-13.1 (E), DIS-46.1 (E), DIS-79.1 (E), J5.12
LED_F: DIS-13.10 (F), DIS-46.10 (F), DIS-79.10 (F), J5.2
LED_G: DIS-13.5 (G), DIS-46.5 (G), DIS-79.5 (G), J5.18

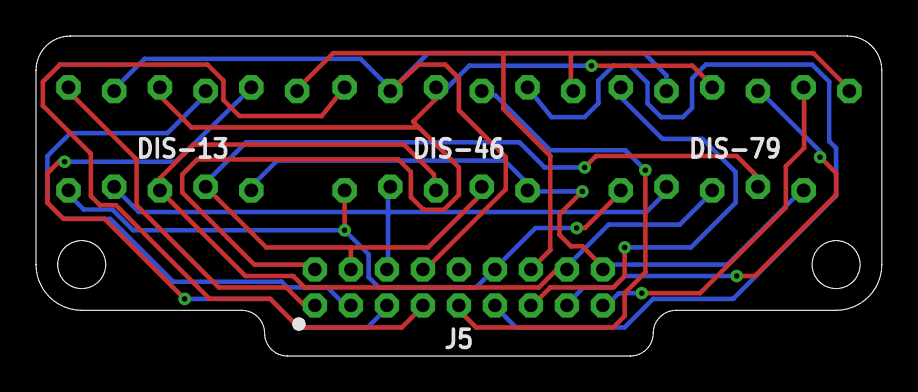
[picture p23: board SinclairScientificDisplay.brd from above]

Board: 2 copper layers, 47.0 x 17.8 mm, 6 parts (0 on the bottom side), 17 nets.

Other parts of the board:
U$1, U$2: HOLE_3-48

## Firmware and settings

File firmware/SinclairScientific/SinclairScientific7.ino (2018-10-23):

// Arduino Port of
//
// TI calculator simulator
// Ken Shirriff, http://righto.com/ti
// Based on patent US3934233
//
// The goal of this project is to run the following simulator: http://righto.com/sinclair
// on an arduino nano powered custom pcb resembling the original Sinclair Scientific Calculator
// @arduinoenigma 2018
//
// To test the up/down buttons press:
// C up X up / up + up - 5.4105-01
// C dn X dn / dn + dn - 4.4200-01
//
// Sinclair Scientific Glitches implemented:
// dot stays on when display turns off, dot gets brighter
// pressing 0 makes dot brighter, other keys not so much
// pressing a key glitches the number displayed,
// pressing 7 glitches more numbers than pressing 1
// pressing C dims the display
// 1 is brighter than 0
// - in mantissa is brighter
//
// Glitches not implemented:
// ???
//
// Other Features:
// press 0 when powering up to display short display self test.
// press 8 when short display self test is showing for longer self test, press C to exit.
// press 1 when powering up for slower than normal speed, display stays lit while computing a result.
// press 2 when powering up for normal speed with display on.
// press 3 when powering up for faster speed with display on.
// press 9 when powering up to toggle showing Sinclair logo at bootup
//
// to enter KITT mode ???
//
// Notes:
// Adjusted refresh delay in updateDisplay() so execution time of ArcCos 0.0001 matches real hardware.
// loop() function get called every 340uS for an effective clock speed of 2.9kHz
//
// uses this fast pin library:
// https://github.com/mikaelpatel/Arduino-GPIO
//

#include "GPIO.h"
#include <EEPROM.h>

#define _steptime 341

//modern LED PCB v5 is Common Anode
//bubble LED PCB v7 is Common Cathode
//recessed modern LED PCB v8 is Common Anode
#define CommonAnode
//#define CommonCathode
//#define BoardV8

//Alignment for SINCLAIR logo
#define AlignRight
//#define AlignLeft

#if defined(CommonAnode)
// The EnableDissassembly option has not been tested with the Common Chathode Display
// and could damage it by taking too long to execute the step function, keeping the display on for too long
//#define EnableDisassembly
#endif

extern void step();

extern void setupFastADC();
extern void allSegmentOutput();
extern void allSegmentInput();
extern void allDigitOutput();
extern void allDigitInput();
extern byte outputDigit(signed char digit, bool decimalpoint = false);
extern void selectDigit(byte digit);
extern byte readKey();
extern byte readKeys();

extern void SinclairLogo();
extern void displaySelfTest(bool longtest = false);
extern void displayRigTest();

//These are the 320 instructions that performed all the tasks on the Sinclair Scientific.
//the rest of this program is to execute and interface these instructions to todays hardware

const unsigned int objectCode[] PROGMEM = {
  1408, 1392, 1792, 1824, 1860, 1808, 1360, 1376,
  518, 1319, 1360, 1376, 9, 1360, 1908, 1072,
  1083, 1075, 1121, 1129, 1073, 1069, 1051, 1840,
  1955, 1840, 516, 1425, 552, 1430, 33, 1792,
  1398, 1631, 1920, 1683, 34, 2003, 1540, 4,
  1399, 1858, 1872, 1538, 4, 1329, 1335, 4,
  1349, 1347, 4, 1443, 676, 1431, 57, 1559,
  4, 1553, 59, 1443, 677, 1839, 1632, 2018,
  65, 2023, 1719, 72, 1730, 71, 1840, 1666,
  1751, 587, 1840, 1754, 78, 1840, 1718, 594,
  1924, 78, 2017, 1713, 89, 1540, 130, 1844,
  1841, 1652, 597, 130, 1730, 95, 1849, 1650,
  114, 1443, 675, 1355, 1345, 130, 1409, 1559,
  105, 1443, 750, 1839, 1632, 1844, 2023, 1719,
  92, 1538, 1537, 116, 1451, 1796, 791, 1908,
  1781, 637, 1722, 1540, 120, 1940, 1786, 119,
  1445, 820, 1754, 512, 1747, 145, 1860, 1751,
  142, 1686, 141, 1799, 1798, 1686, 1558, 132,
  132, 1908, 1751, 662, 1686, 1686, 1558, 152,
  1441, 614, 1392, 1334, 1408, 1750, 161, 1559,
  159, 1568, 4, 1351, 1355, 1686, 681, 1908,
  165, 1801, 1689, 1824, 1445, 180, 1447, 179,
  1568, 1819, 185, 1565, 1820, 1924, 2011, 1693,
  738, 1888, 1888, 1888, 2012, 1696, 1936, 1936,
  1936, 1872, 1872, 1872, 2012, 1584, 1724, 1920,
  1920, 1920, 1445, 183, 1561, 1447, 210, 1779,
  697, 220, 1451, 727, 1732, 185, 220, 1754,
  1844, 1764, 1844, 185, 1904, 1904, 1904, 1904,
  1904, 130, 1447, 233, 1616, 1600, 1808, 1411,
  100, 1451, 236, 1632, 1840, 130, 1445, 251,
  1750, 760, 1751, 759, 1908, 1686, 240, 1860,
  1794, 1864, 1864, 1824, 2003, 1636, 1924, 1924,
  1700, 1431, 823, 2009, 1787, 253, 1993, 2036,
  1723, 1920, 1920, 1920, 1920, 1588, 1844, 1445,
  814, 1600, 1479, 1447, 765, 1572, 1796, 1806,
  1764, 797, 1700, 1562, 280, 1571, 803, 1860,
  1631, 1892, 280, 1807, 1443, 808, 130, 10,
  1572, 1796, 1904, 1904, 1794, 61, 1572, 1796,
  1803, 1652, 1844, 117, 1908, 1335, 251, 1693,
  253, 1565, 1860, 1563, 2036, 1844, 1411, 790
};

#define NUMBER_OF_MASKS 16
#define MASK_LENGTH 12

const char masks [][MASK_LENGTH] PROGMEM = {
  {"00000000000"}, // M0
  {"5          "}, // M1
  {"  00       "}, // M2
  {"    1      "}, // M3
  {"    0000000"}, // M4
  {"          1"}, // M5
  {"  01       "}, // M6
  {" 5         "}, // M7
  {"000000     "}, // M8
  {"0001       "}, // M9
  {"    0000001"}, // M10
  {"     1     "}, // M11
  {"    00005  "}, // M12
  {"    00001  "}, // M13
  {"    4      "}, // M14
  {"    0      "}, // M15
};

// OPS WITH K: 1:AAKA 2:AAKC 5:ACKA 6:ACKB 9: 11:
//const unsigned long LISTOPSWITHK = 000111100000001111010101001100110b;
const unsigned long LISTOPSWITHK = 1007135334;

signed char digits[9] = {0, 0, 0, 0, 0, 0, 0, 0, 0};

// keysKN and keysKO must match PrintableKeys on DisplayAndKeys.ino
//const char PrintableKeys[19] = "12+E0v-378X654/9^C";

const char keysKN[10] = {'1', '2', '3', '4', '5', '6', '7', '8', '9', 0};
const char keysKO[10] = {'C', 'v', '+', '-', '/', 'X', '^', 'E', '0', 0};
//const char keysKP[10] = {0, 0, 0, 0, 0, 0, 0, 0, 0, 0};

// to use with keyPressed
#define DK 1

// ORIGINAL SINCLAIR DATA
struct SinclairData_t
{
  boolean sinclair = true;

  // Important: Array order matches display order, not bit order.
  // I.e. a[0] is high-order digit S10, a[10] is low-order digit S0.
  signed char  a[11] = {0, 0, 0, 0, 0, 0, 0, 0, 0, 0, 0};    // Register A
  signed char  b[11] = {0, 0, 0, 0, 0, 0, 0, 0, 0, 0, 0};    // Register B
  signed char  c[11] = {0, 0, 0, 0, 0, 0, 0, 0, 0, 0, 0};    // Register C
  signed char af[11] = {0, 0, 0, 0, 0, 0, 0, 0, 0, 0, 0};    // Flags A
  signed char bf[11] = {0, 0, 0, 0, 0, 0, 0, 0, 0, 0, 0};    // Flags A

  signed char  d[11] = {0, 1, 1, 1, 1, 1, 1, 1, 1, 1, 1};

  byte dActive = 1;          // Currently active D value 1-11. d[dActive-1] == 0
  signed char cc = 0;
  byte keyPressed = 0;

  byte keyStrobeKN = 0;      //
  byte keyStrobeKO = 0;      // '
  byte keyStrobeKP = 0;      // '

  unsigned int address = 0;  // PROGRAM COUNTER
  byte display = 1;          // Flag for display on
  char mask[MASK_LENGTH];

  byte showwork = 0;         // when 0, display flag controls LED, when 1, LED always on
  byte speed = 1;            // 0 - slow 1 - normal 2 - fast
  int steptime = _steptime;  // the step() function will take this many microseconds to execute, uses a delay to eat remaining time if it finishes faster.
  int steptime1 = _steptime; // backup

  bool resetinprogress = false;
  byte segmentslit = 0;

  byte lastSelectDigit = 0;

  bool timeinit = false;
  unsigned long nextentrytime = 0;

} SinclairData;

const byte DisplayOrder[9] = {1, 7, 8, 9, 2, 3, 4, 5, 6};

void updateDisplay()
{
  byte displayon = SinclairData.display + SinclairData.showwork;

  bool dp = false; // needed for logic below, keep initialized to false

  byte showdigit;
  byte digitoff = 99;
  byte digiton = 99;
  byte digitpos = 0;

  digitpos = DisplayOrder[SinclairData.dActive - 1];

  switch (digitpos)
  {
    case 1:
      digiton = (SinclairData.a[0] == 0) ? 99 : 10;
      break;

    case 2:
      digiton = SinclairData.a[4];
      break;

    case 3:
      digiton = SinclairData.a[5];
      break;

    case 4:
      digiton = SinclairData.a[6];
      break;

    case 5:
      digiton = SinclairData.a[7];
      break;

    case 6:
      digiton = SinclairData.a[8];
      break;

    case 7:
      digiton = (SinclairData.a[1] == 0) ? 99 : 10;
      break;

    case 8:
      digiton = SinclairData.a[2];
      break;

    case 9:
      digiton = SinclairData.a[3];
      break;
  }

  // SINCLAIR behavior: turn decimal point on automatically at fixed position
  // dot stays on whether the rest of the display is on or off
  // this logic attempts to make optimizer do variable copy on dp1 = dp2 and dp1 = dp below.
  if (digitpos == 2) {
    dp = true;
  }
  else
  {
    dp = false;
  }

  // attempt to have this block take same time to run whether a digit or blank is displayed
  if (displayon) {
    showdigit = digiton;
  }
  else {
    showdigit = digitoff;

    // SINCLAIR behavior: dot goes brighter when display is off.
    // only needed in common anode hardware
#if defined(CommonAnode)
    //(control brightness of dot, 2=brighter .. 8=dimmer)
    if (digitpos > 5) // set to greater than 2 to allow column 1 to be read for C and column 2 to display dot
    {
      digitpos = 2;
      dp = true;
    }
#endif

  }

  SinclairData.segmentslit = outputDigit(showdigit, dp);
  selectDigit(digitpos);

  // adjust case 1 for the following:
  // Tan 8 takes 11.6 seconds
  // Sin 1 takes about 7.3 seconds.
  // Arccos .2 takes about 13.6 seconds
  // Arctan 1 takes about 6.6 seconds
  // Arccos of a very small value (e.g. 0.0001) goes into an almost-infinite loop and takes 1 minute, 38 seconds to complete

}

void setup()
{
  // put your setup code here, to run once:

  Serial.begin(2000000);

  // makes it easier to see if an arduino is programmed or not
  Serial.print(F("SINCLAIR v7 092318"));
#if defined(CommonAnode)
  Serial.print(F(" -Common Anode"));
#endif
#if defined(CommonCathode)
  Serial.print(F(" -Common Cathode"));
#endif
#if defined(BoardV8)
  Serial.print(F(" -Common Anode V8"));
#endif
#if defined(AlignRight)
  Serial.print(F(" -Aligned Right"));
#endif
#if defined(AlignLeft)
  Serial.print(F(" -Aligned Left"));
#endif
  Serial.println(F(""));

  setupFastADC();

  allSegmentOff();
  allSegmentOutput();

  allDigitOff();
  allDigitOutput();

  int actual;
  boolean failure = false;

  byte showlogo = EEPROM.read(1);
  if (showlogo != 0) {
    showlogo = 255;
    SinclairLogo();
    //CasioLogo();
  }
  showlogo ^= 255;

  char key = readKeys();
  SinclairData.showwork = 1;  //takes effect only on 1,2,3

  switch (key)
  {
    case '0':
      displaySelfTest();
      SinclairData.speed = 1;
      SinclairData.showwork = 0; //normal speed, display off during calculations
      break;
    case '1':
      SinclairData.speed = 0;  //slow, display on
      SinclairData.steptime1 = 400;
      SinclairData.steptime = 400;
      break;
    case '2':
      SinclairData.speed = 1;  //normal, display on
      break;
    case '3':
      SinclairData.speed = 2;  //fast, display on
      SinclairData.steptime1 = 200;
      SinclairData.steptime = 200;
      break;
    case '9':
      EEPROM.write(1, showlogo); // break has been omitted on purpose so speed and showwork are the normal values
      if (showlogo != 0) {
        SinclairLogo();
      }
    default:
      SinclairData.speed = 1;
      SinclairData.showwork = 0; //normal speed, display off during calculations
      break;
  }
}

// timing the loop function using the micros() function, finds it executes every 340uS, for a 2.9kHz clock speed

void loop()
{
  // put your main code here, to run repeatedly:
  char key;

  if (!SinclairData.timeinit)
  {
    SinclairData.nextentrytime = micros() + SinclairData.steptime;
    SinclairData.timeinit = true;
  }
  else
  {
    do
    {

    } while (micros() < SinclairData.nextentrytime);
    SinclairData.nextentrytime += SinclairData.steptime;
  }

  step();

  updateDisplay();

  key = readKey();

  if (SinclairData.resetinprogress)
  {
    // SINCLAIR behavior: makes the display dim when C is pressed, SinclairData.steptime must be reduced below 148 for this delay to take effect.
    delayMicroseconds(120); // sets brightness when C is pressed. smaller=dimmer

    allSegmentOff();
    if (SinclairData.address > 8) {
      SinclairData.resetinprogress = false;
      SinclairData.timeinit = false;
      SinclairData.steptime = SinclairData.steptime1;
    }
  }

  if (key == 'C') {
    if (SinclairData.resetinprogress == false) {
      SinclairData.address = 0;
      SinclairData.keyStrobeKN = 0;
      SinclairData.keyStrobeKO = 0;
      SinclairData.keyStrobeKP = 0;
      SinclairData.dActive = 1;
      SinclairData.steptime = 5; // speed up step() function so digit brightness can be controlled via smaller delayMicroseconds()
      SinclairData.resetinprogress = true;
    }
  }

  //detect numbers with 4 segments or less lit and turn them off sooner
  //this reduces the visible difference between a 1 and an 8 (without this 1 is normally brighter)
  //only affects commonCathode display
#if defined(CommonCathode)
  if (SinclairData.segmentslit < 4)
  {
    // 1 7
    delayMicroseconds(140);
    allDigitOff();
  }
  else if (SinclairData.segmentslit < 5)
  {
    // 4
    delayMicroseconds(180);
    allDigitOff();
  }
#endif

}

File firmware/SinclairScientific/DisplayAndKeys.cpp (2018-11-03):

#include "DisplayAndKeys.h"
#include "SinclairScientific.h"

// http://forum.arduino.cc/index.php?topic=6549.msg51570#msg51570
// defines for setting and clearing register bits
#ifndef cbi
#define cbi(sfr, bit) (_SFR_BYTE(sfr) &= ~_BV(bit))
#endif
#ifndef sbi
#define sbi(sfr, bit) (_SFR_BYTE(sfr) |= _BV(bit))
#endif

void setupFastADC()
{
  // http://forum.arduino.cc/index.php?topic=6549.msg51570#msg51570
  // set prescale to 16
//  sbi(ADCSRA, ADPS2) ;
//  cbi(ADCSRA, ADPS1) ;
//  cbi(ADCSRA, ADPS0) ;
}

void allSegmentOutput()
{
  pinMode(SegmentA, OUTPUT);
  pinMode(SegmentB, OUTPUT);
  pinMode(SegmentC, OUTPUT);
  pinMode(SegmentD, OUTPUT);
  pinMode(SegmentE, OUTPUT);
  pinMode(SegmentF, OUTPUT);
  pinMode(SegmentG, OUTPUT);
  pinMode(SegmentDP, OUTPUT);
}

void allSegmentInput()
{
  pinMode(SegmentA, INPUT);
  pinMode(SegmentB, INPUT);
  pinMode(SegmentC, INPUT);
  pinMode(SegmentD, INPUT);
  pinMode(SegmentE, INPUT);
  pinMode(SegmentF, INPUT);
  pinMode(SegmentG, INPUT);
  pinMode(SegmentDP, INPUT);
}

void allDigitOutput()
{
  pinMode(Digit1, OUTPUT);
  pinMode(Digit2, OUTPUT);
  pinMode(Digit3, OUTPUT);
  pinMode(Digit4, OUTPUT);
  pinMode(Digit5, OUTPUT);
  pinMode(Digit6, OUTPUT);
  pinMode(Digit7, OUTPUT);
  pinMode(Digit8, OUTPUT);
  pinMode(Digit9, OUTPUT);
}

void allDigitInput()
{
  pinMode(Digit1, INPUT);
  pinMode(Digit2, INPUT);
  pinMode(Digit3, INPUT);
  pinMode(Digit4, INPUT);
  pinMode(Digit5, INPUT);
  pinMode(Digit6, INPUT);
  pinMode(Digit7, INPUT);
  pinMode(Digit8, INPUT);
  pinMode(Digit9, INPUT);
}

void allSegmentOff()
{
  digitalWrite(SegmentA, SegmentOff);
  digitalWrite(SegmentB, SegmentOff);
  digitalWrite(SegmentC, SegmentOff);
  digitalWrite(SegmentD, SegmentOff);
  digitalWrite(SegmentE, SegmentOff);
  digitalWrite(SegmentF, SegmentOff);
  digitalWrite(SegmentG, SegmentOff);
  digitalWrite(SegmentDP, SegmentOff);
}

void allDigitOff()
{
  digitalWrite(Digit1, DigitOff);
  digitalWrite(Digit2, DigitOff);
  digitalWrite(Digit3, DigitOff);
  digitalWrite(Digit4, DigitOff);
  digitalWrite(Digit5, DigitOff);
  digitalWrite(Digit6, DigitOff);
  digitalWrite(Digit7, DigitOff);
  digitalWrite(Digit8, DigitOff);
  digitalWrite(Digit9, DigitOff);
}

byte outputDigit(signed char digit, bool decimalpoint) {

  byte segmentslit = 0;

  allDigitOff();

  if (decimalpoint)
  {
    //segmentslit++;
    digitalWrite(SegmentDP, SegmentOn);
  }
  else
  {
    digitalWrite(SegmentDP, SegmentOff);
  }

  switch (digit) {
    case 0:
      digitalWrite(SegmentA, SegmentOn);
      digitalWrite(SegmentB, SegmentOn);
      digitalWrite(SegmentC, SegmentOn);
      digitalWrite(SegmentD, SegmentOn);
      digitalWrite(SegmentE, SegmentOn);
      digitalWrite(SegmentF, SegmentOn);
      digitalWrite(SegmentG, SegmentOff);
      segmentslit += 6;
      break;
    case 1:
      digitalWrite(SegmentA, SegmentOff);
      digitalWrite(SegmentB, SegmentOn);
      digitalWrite(SegmentC, SegmentOn);
      digitalWrite(SegmentD, SegmentOff);
      digitalWrite(SegmentE, SegmentOff);
      digitalWrite(SegmentF, SegmentOff);
      digitalWrite(SegmentG, SegmentOff);
      segmentslit += 2;
      break;
    case 2:
      digitalWrite(SegmentA, SegmentOn);
      digitalWrite(SegmentB, SegmentOn);
      digitalWrite(SegmentC, SegmentOff);
      digitalWrite(SegmentD, SegmentOn);
      digitalWrite(SegmentE, SegmentOn);
      digitalWrite(SegmentF, SegmentOff);
      digitalWrite(SegmentG, SegmentOn);
      segmentslit += 5;
      break;
    case 3:
      digitalWrite(SegmentA, SegmentOn);
      digitalWrite(SegmentB, SegmentOn);
      digitalWrite(SegmentC, SegmentOn);
      digitalWrite(SegmentD, SegmentOn);
      digitalWrite(SegmentE, SegmentOff);
      digitalWrite(SegmentF, SegmentOff);
      digitalWrite(SegmentG, SegmentOn);
      segmentslit += 5;
      break;
    case 4:
      digitalWrite(SegmentA, SegmentOff);
      digitalWrite(SegmentB, SegmentOn);
      digitalWrite(SegmentC, SegmentOn);
      digitalWrite(SegmentD, SegmentOff);
      digitalWrite(SegmentE, SegmentOff);
      digitalWrite(SegmentF, SegmentOn);
      digitalWrite(SegmentG, SegmentOn);
      segmentslit += 4;
      break;
    case 5:
      digitalWrite(SegmentA, SegmentOn);
      digitalWrite(SegmentB, SegmentOff);
      digitalWrite(SegmentC, SegmentOn);
      digitalWrite(SegmentD, SegmentOn);
      digitalWrite(SegmentE, SegmentOff);
      digitalWrite(SegmentF, SegmentOn);
      digitalWrite(SegmentG, SegmentOn);
      segmentslit += 5;
      break;
    case 6:
      digitalWrite(SegmentA, SegmentOn);
      digitalWrite(SegmentB, SegmentOff);
      digitalWrite(SegmentC, SegmentOn);
      digitalWrite(SegmentD, SegmentOn);
      digitalWrite(SegmentE, SegmentOn);
      digitalWrite(SegmentF, SegmentOn);
      digitalWrite(SegmentG, SegmentOn);
      segmentslit += 6;
      break;
    case 7:
      digitalWrite(SegmentA, SegmentOn);
      digitalWrite(SegmentB, SegmentOn);
      digitalWrite(SegmentC, SegmentOn);
      digitalWrite(SegmentD, SegmentOff);
      digitalWrite(SegmentE, SegmentOff);
      digitalWrite(SegmentF, SegmentOff);
      digitalWrite(SegmentG, SegmentOff);
      segmentslit += 3;
      break;
    case 8:
      digitalWrite(SegmentA, SegmentOn);
      digitalWrite(SegmentB, SegmentOn);
      digitalWrite(SegmentC, SegmentOn);
      digitalWrite(SegmentD, SegmentOn);
      digitalWrite(SegmentE, SegmentOn);
      digitalWrite(SegmentF, SegmentOn);
      digitalWrite(SegmentG, SegmentOn);
      segmentslit += 7;
      break;
    case 9:
      digitalWrite(SegmentA, SegmentOn);
      digitalWrite(SegmentB, SegmentOn);
      digitalWrite(SegmentC, SegmentOn);
      digitalWrite(SegmentD, SegmentOff);
      digitalWrite(SegmentE, SegmentOff);
      digitalWrite(SegmentF, SegmentOn);
      digitalWrite(SegmentG, SegmentOn);
      segmentslit += 5;
      break;
    case 10:
      digitalWrite(SegmentA, SegmentOff);
      digitalWrite(SegmentB, SegmentOff);
      digitalWrite(SegmentC, SegmentOff);
      digitalWrite(SegmentD, SegmentOff);
      digitalWrite(SegmentE, SegmentOff);
      digitalWrite(SegmentF, SegmentOff);
      digitalWrite(SegmentG, SegmentOn);
      segmentslit += 1;
      break;
    case 99:
      digitalWrite(SegmentA, SegmentOff);
      digitalWrite(SegmentB, SegmentOff);
      digitalWrite(SegmentC, SegmentOff);
      digitalWrite(SegmentD, SegmentOff);
      digitalWrite(SegmentE, SegmentOff);
      digitalWrite(SegmentF, SegmentOff);
      digitalWrite(SegmentG, SegmentOff);
      break;
    default:
      allSegmentOff();
      break;
  }

  return segmentslit;
}
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

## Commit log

2018-10-04 Initial commit. Started making hardware changes.
    [SinclairScientific.brd, SinclairScientific.sch]
2018-10-07 Added more to schematic, started PCB placement, still WIP
    [SinclairScientific.brd, SinclairScientific.sch]
2018-10-18 Schematic nearly finalized, still working on board dimensions and component placement
    [SinclairScientific.brd, SinclairScientific.sch]
2018-10-23 Moved displays to their own sch/brd files, nearly finished routing main board
    [SinclairScientific.brd, SinclairScientific.sch]
2018-10-23 Finished routing
    [SinclairScientific.brd, SinclairScientificDisplay.brd, SinclairScientificDisplay.sch]
2018-10-23 Added some silkscreen labels and logo
    [SinclairScientific.brd, SinclairScientific.sch, SinclairScientificDisplay.brd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]
2018-11-03 Fixed some hardware issues found in testing v1B prototype
    [SinclairScientific v1B - BOM.csv, SinclairScientific.brd, SinclairScientificDisplay.brd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]
2018-11-05 Converted local library to managed library. Fixed more hardware issues found from testing v1B prototype.
    [SinclairScientific.brd, SinclairScientific.sch, SinclairScientificCover.brd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]
2018-11-07 Changed on/off switch to SMD type, fixed some DFM issues
    [SinclairScientific v1B - BOM.csv, SinclairScientific.brd, SinclairScientific.sch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]
2018-11-07 Changed button spacing, finalized rev 1C layouts
    [SinclairScientific.brd, SinclairScientific.sch, SinclairScientificCover.brd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]
2018-11-09 Updated BOM and added BOM attributes to schematic
    [SinclairScientific v1B - BOM.csv, SinclairScientific v1C - BOM.csv, SinclairScientific.brd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]
2018-11-12 Finalized top layer of faceplate board
    [SinclairScientificCover.brd]
2018-11-22 Increased coverplate silkscreen text width
    [SinclairScientific.brd, SinclairScientificCover.brd]
2018-11-22 Added STEP files for each board
    [display-board.step, faceplate.step]
2018-11-22 Added artwork used to create faceplate PCB silkscreen text
2018-12-01 Updated firmware to prevent LED drive pins from being Hi-Z on startup, which can cause LEDs to be on
    [DisplayTestFunctions.cpp, SinclairScientific.ino]
2018-12-01 Added toolchain files (modified version of Adafruit's SAMD library)
    [arduino_zero.cfg]
2018-12-01 Added PDFs of schematics for easier reference
2018-12-14 Updated readme text and added print version of manual.

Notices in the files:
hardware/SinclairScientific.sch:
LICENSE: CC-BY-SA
